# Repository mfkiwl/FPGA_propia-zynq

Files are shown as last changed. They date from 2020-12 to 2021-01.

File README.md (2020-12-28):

# FPGA_propia
 En este repositorio se subirán los ficheros que permitirán crear una FPGA basada en Zynq-7000

Todo el desarrollo está hecho con KiCad (software libre) para que cualquiera pueda replicarla o mejorarla a su gusto con los ficheros que se van a publicar

## Libreria
El fichero tiene una librería llamada 'Zynq-7000' en la que está el symbol de un XC7Z010 del cual se implementará la versión CLG400 (400 pines en formato de soldadura BGA) 
## XC7Z010-BUENO
El símbolo consta de 9 partes, de las que se va a describir su selección a continuación
### - _Símbolo A_
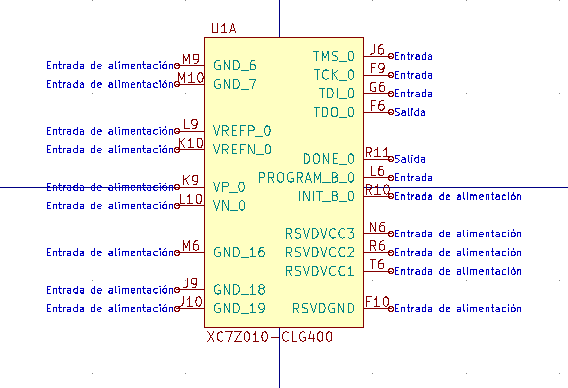
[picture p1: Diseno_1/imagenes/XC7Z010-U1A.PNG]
diseno_A


En este símbolo se reflejan los pines de referencia, además de los pines de depuración TMS, TCK, TDI y TDO. Estos pines pueden necesitar de un cable depurar para cargar el programa o de un USB OTG, que permita evitar tener que usar un cable depurador.

### - _Símbolo B_
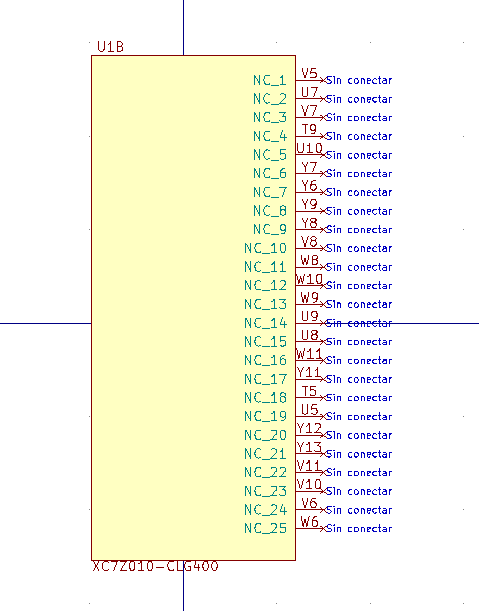
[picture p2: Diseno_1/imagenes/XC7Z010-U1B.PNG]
diseno_B


En este símbolo se reflejan los pines que no tienen conexión

### - _Símbolo c_
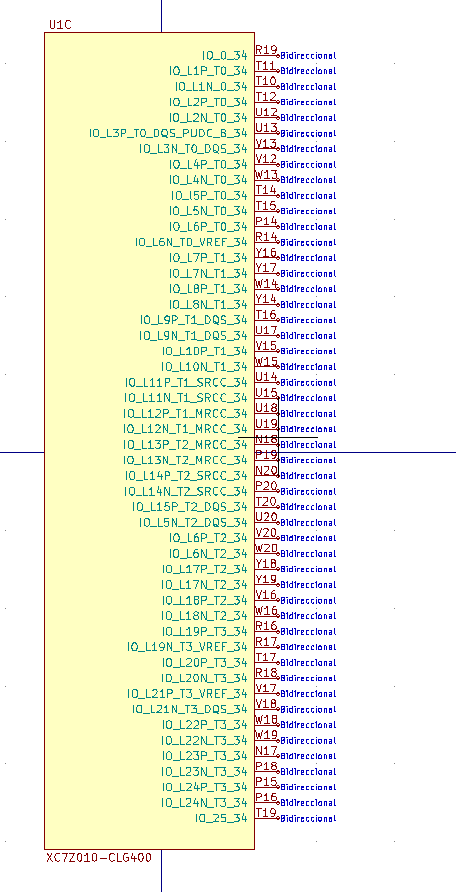
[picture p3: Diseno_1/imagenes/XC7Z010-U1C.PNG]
diseno_C


En este símbolo se reflejan los pines de entrada/salida que se podrán configurar como se quiera

### - _Símbolo D_
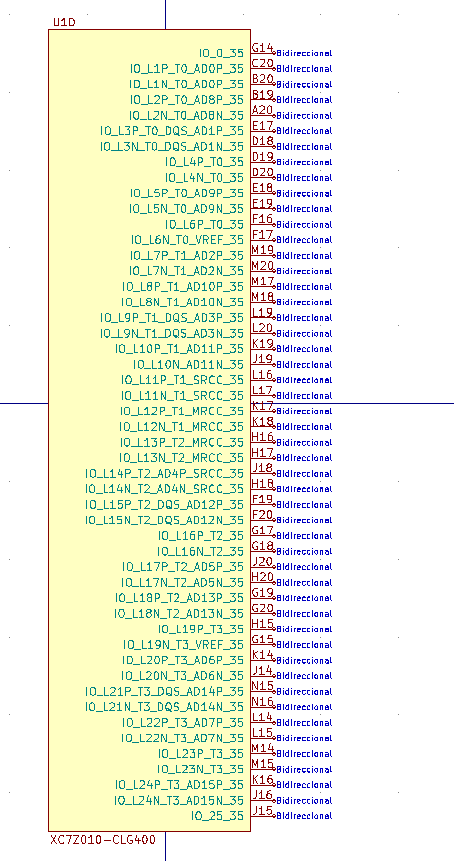
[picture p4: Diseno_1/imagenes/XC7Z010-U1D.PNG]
diseno_D


En este símbolo se reflejan los pines de entrada/salida que se podrán configurar como se quiera

### - _Símbolo E_
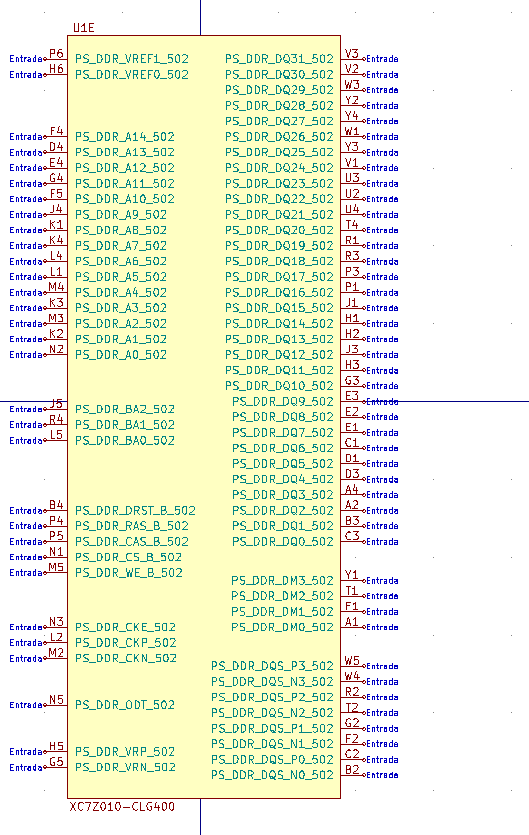
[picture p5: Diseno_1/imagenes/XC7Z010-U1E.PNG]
diseno_E


En este símbolo se reflejan los pines que van a ir a la/las memoria ram. A los pines de la ram se pueden unir varias memorias para aumentar su tamaño.

### - _Símbolo F_
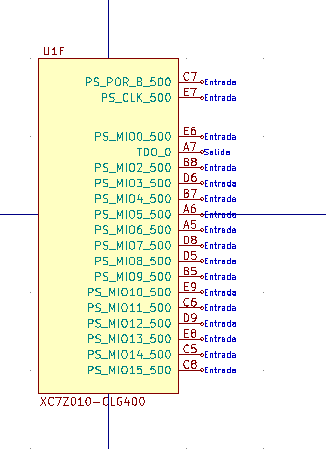
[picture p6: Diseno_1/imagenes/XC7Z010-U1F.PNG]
diseno_F


En este símbolo se reflejan los pines MIO

### - _Símbolo G_
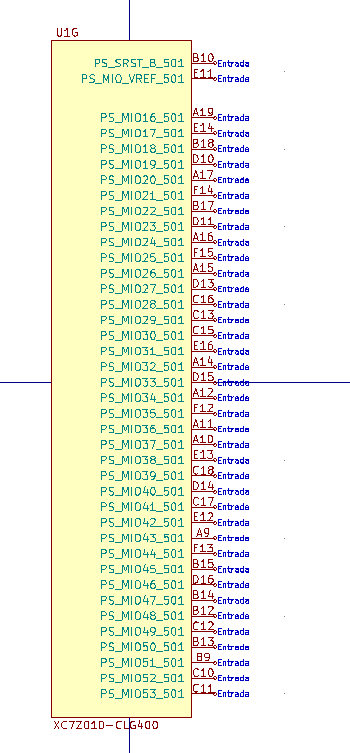
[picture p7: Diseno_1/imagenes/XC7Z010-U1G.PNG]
diseno_G


En este símbolo se reflejan los pines MIO continuación de los anteriores

### - _Símbolo H_
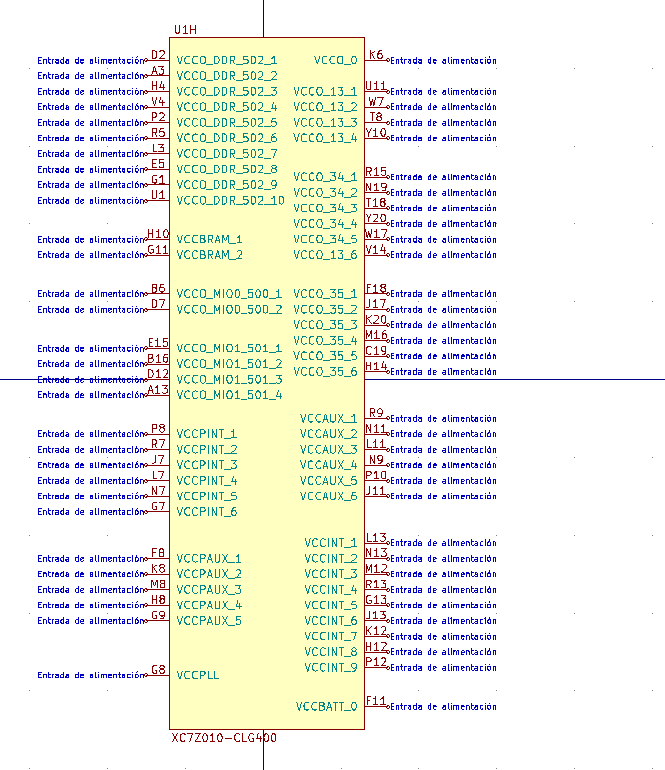
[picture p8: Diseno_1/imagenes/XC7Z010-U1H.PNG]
diseno_F


En este símbolo se reflejan las alimentaciones de cada parte del integrado. Hay que tener en cuenta que cada parte tiene una alimentación distinta, la VCCO_BRAM y los VCCO_PINT de 1V, los VCCO_MIO 3.3V, los VCCO_DDR de 1.35V y los VCCAUX y los VCCPAUX de 1.8V

### - _Símbolo I_
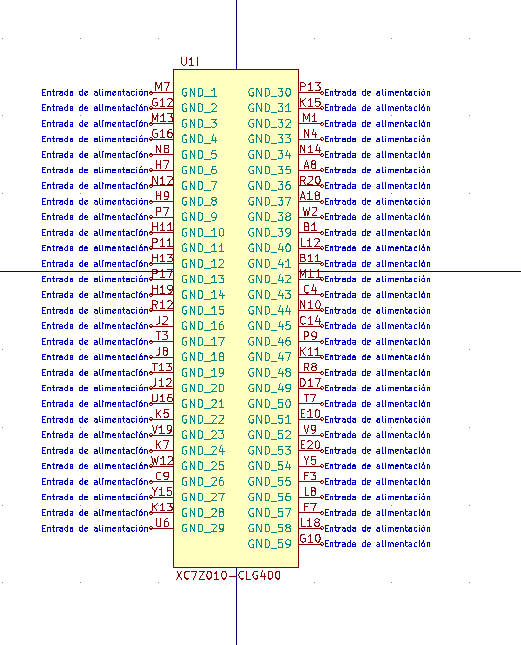
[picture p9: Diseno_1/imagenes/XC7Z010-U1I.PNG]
diseno_I


En este símbolo se reflejan las masas de todo el integrado. Todas las masas van unidas a mismo punto.

### - *Formato del integrado*
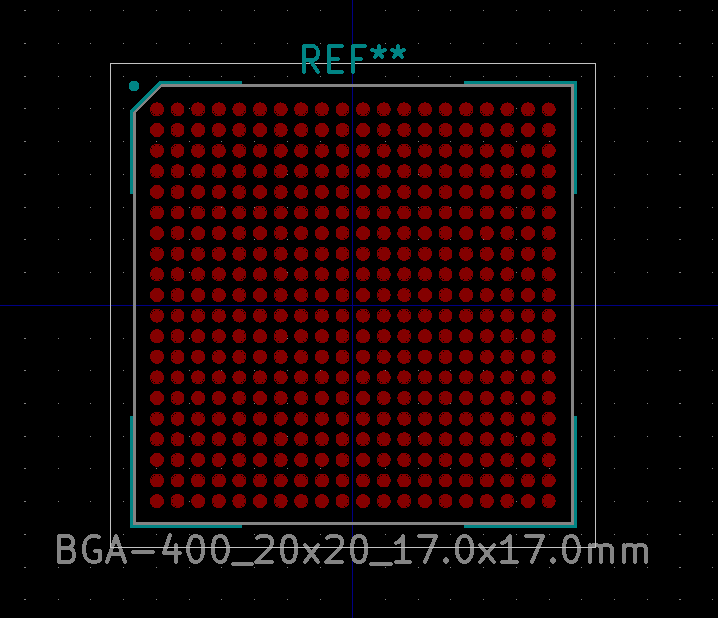
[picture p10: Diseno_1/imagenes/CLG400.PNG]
CLG400


En esta imagen se refleja como es el integrado CLG400 de 400 pines(20x20) para BGA

*** Toda la documentación del frabicante se puede obtener del siguiente enlace: ***
Documentación para el empaquetado: https://www.xilinx.com/support/documentation/user_guides/ug865-Zynq-7000-Pkg-Pinout.pdf
Documentación de los pines: https://www.xilinx.com/support/packagefiles/z7packages/xc7z010clg400pkg.txt

## Memoria RAM
Para la memoria ram se utiliza una MT4K256M16TW-107:P
### Datasheet
http://www.farnell.com/datasheets/3151560.pdf
### Símbolo
El símbolo utilizado es el siguiente
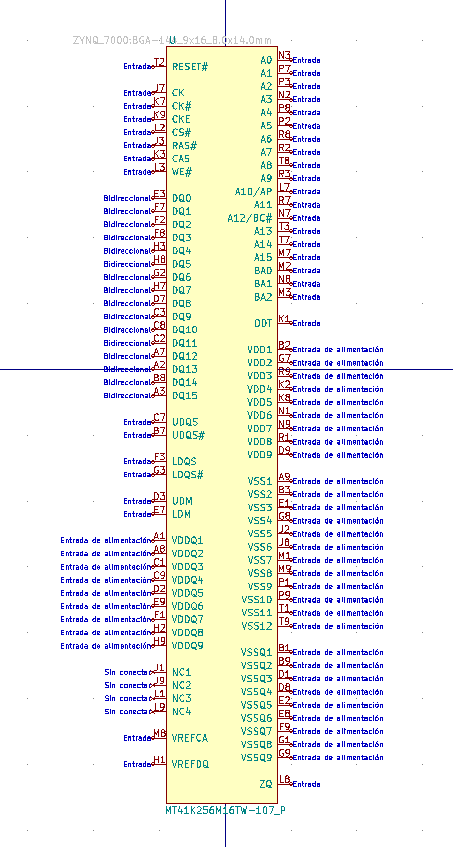
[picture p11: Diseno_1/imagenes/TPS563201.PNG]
Memoria Ram

### Huella
La huella de la memoria ram consta de una matriz de 6x16 que está fragmetada en dos partes separadas por una zona en la que van 3 columnas de pines vacías.
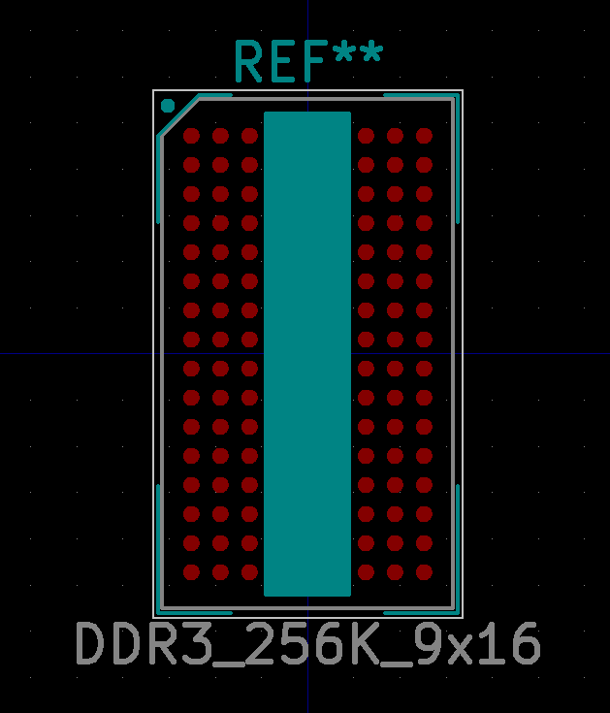
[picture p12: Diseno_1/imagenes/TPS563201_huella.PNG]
Huella Memoria Ram


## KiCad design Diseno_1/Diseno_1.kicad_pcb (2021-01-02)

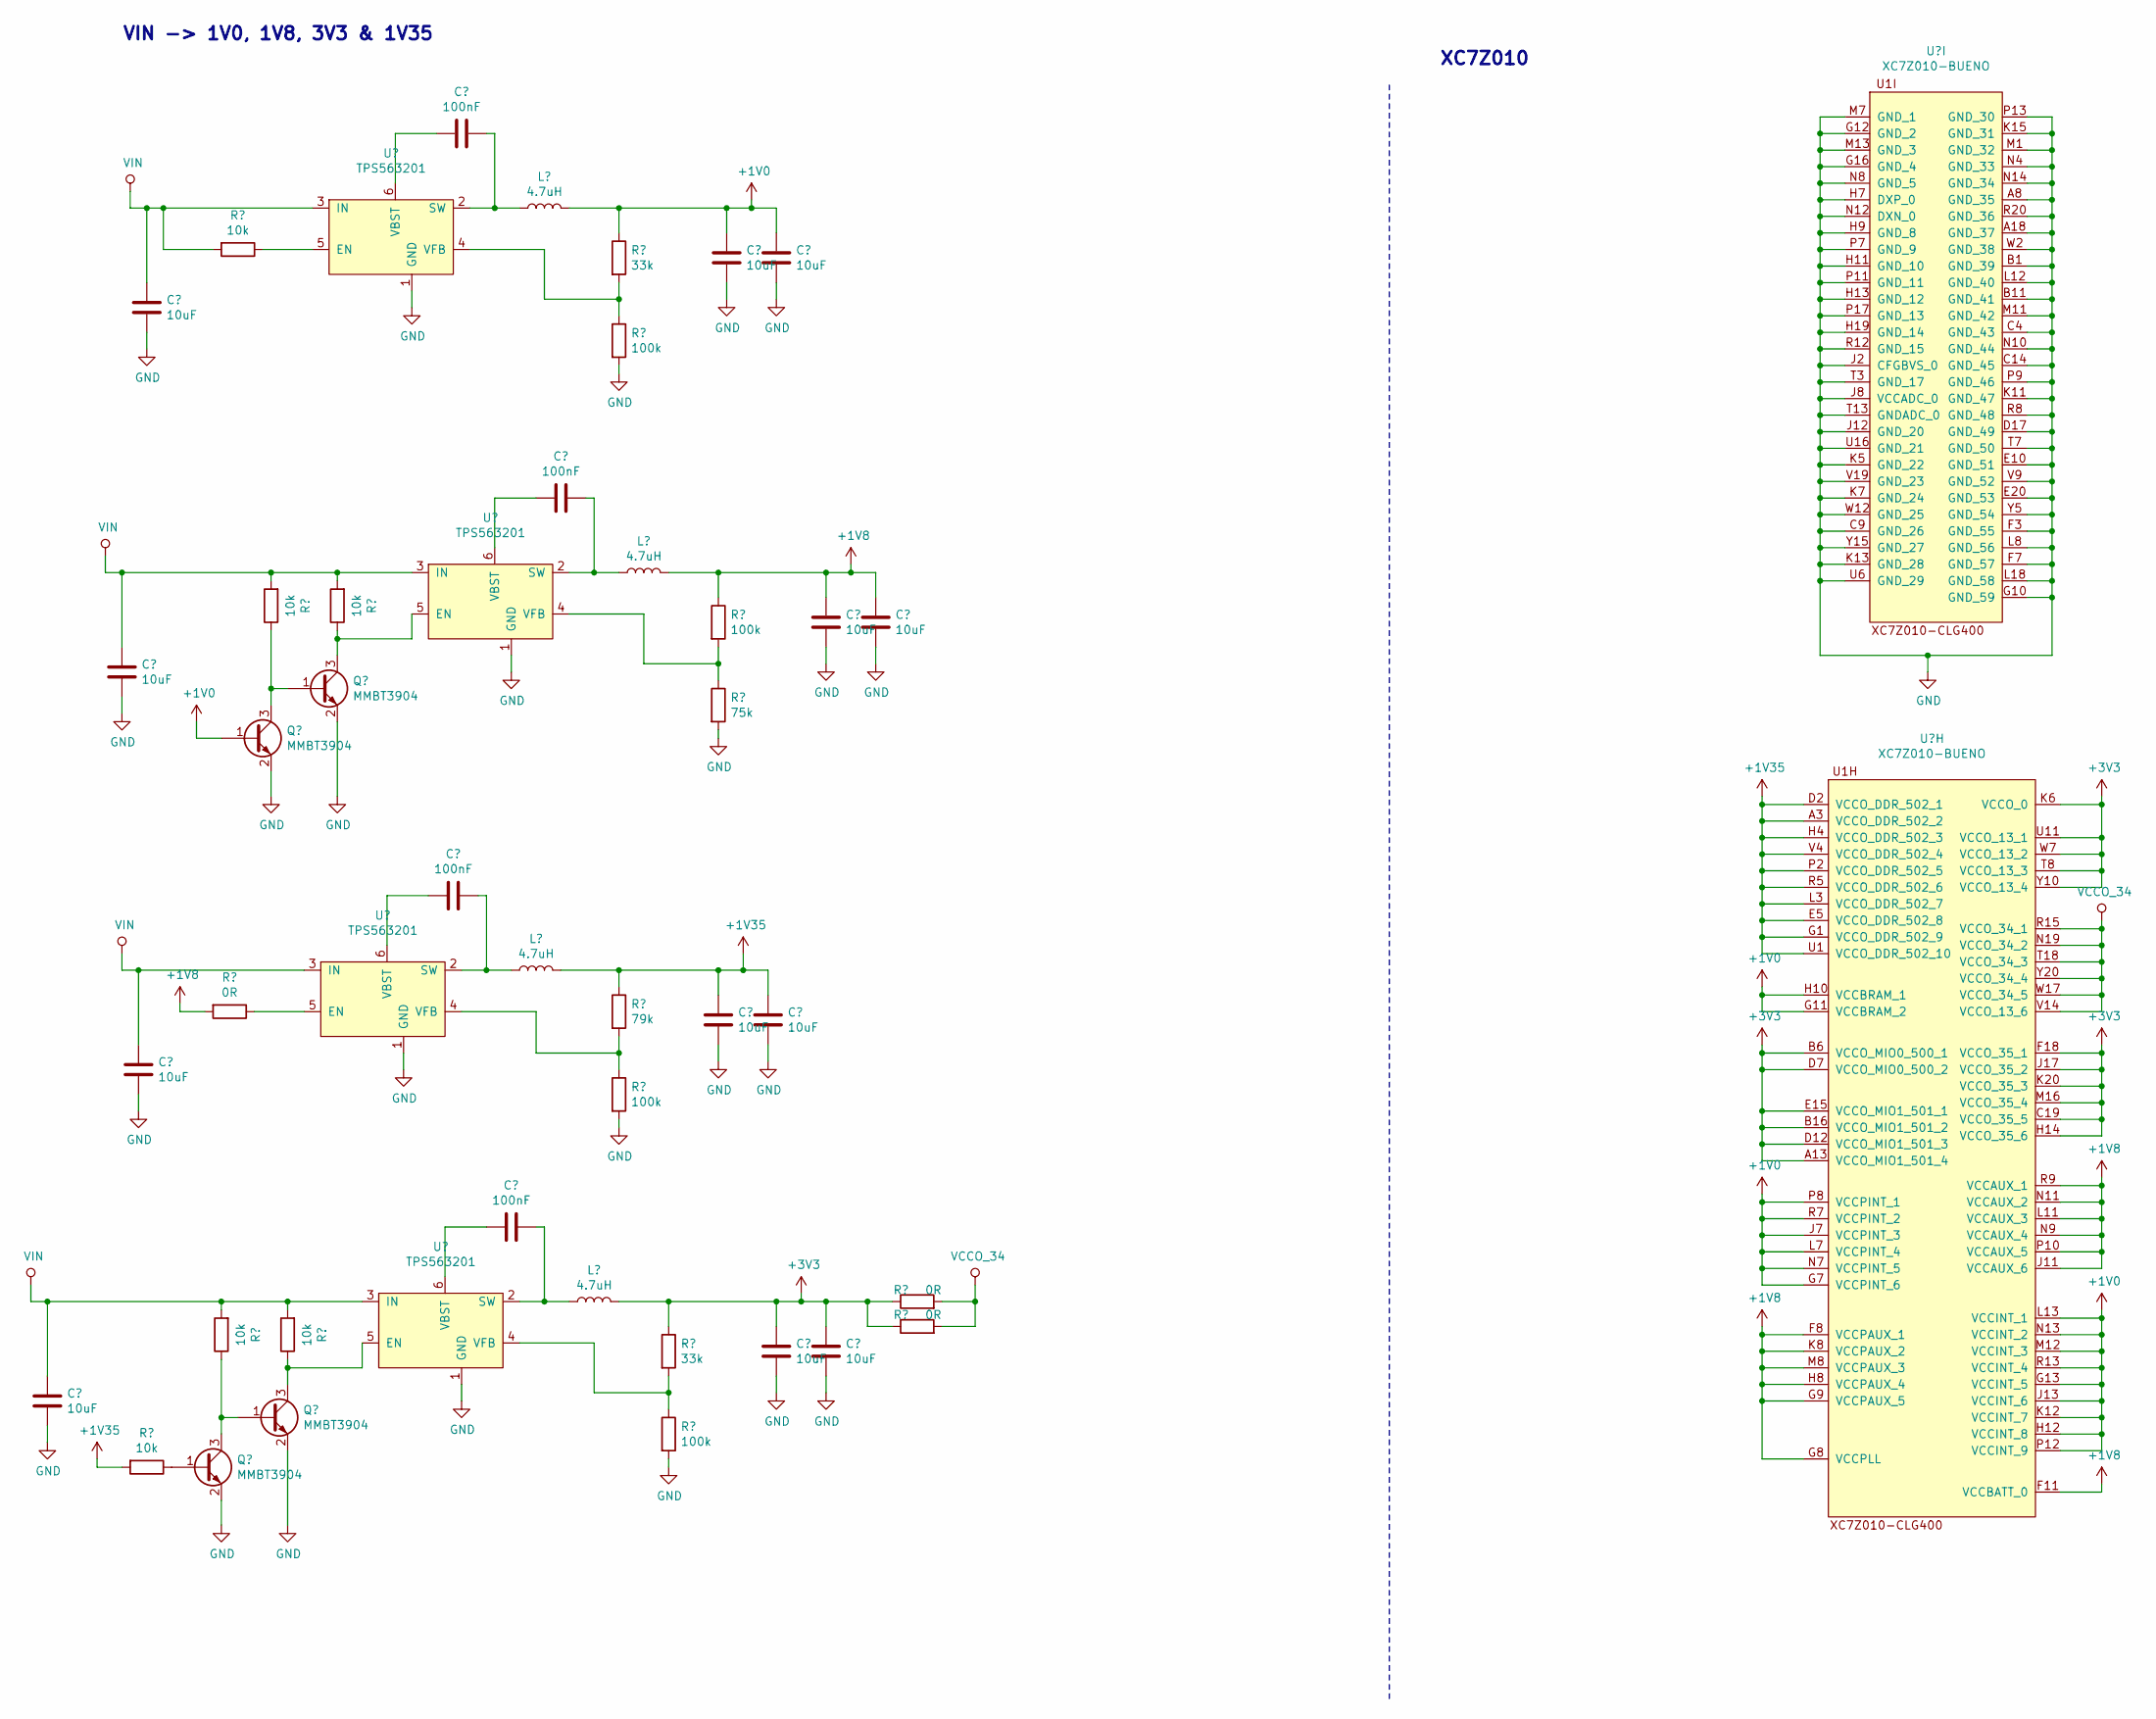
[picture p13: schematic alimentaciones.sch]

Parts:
C1, C2, C3, C4, C9, C10, C11, C12, C13, C14, C15, C16: 10uF; C_0805_2012Metric
C5, C6, C7, C8: 100nF; C_0805_2012Metric
L1, L2, L3, L4: 4.7uH; L_0805_2012Metric
Q1, Q2, Q3, Q4: MMBT3904; SOT-23
R1, R2, R4, R5, R6, R7: 10k; R_0805_2012Metric
R3, R16, R17: 0R; R_0805_2012Metric
R8, R12: 33k; R_0805_2012Metric
R9, R11, R13, R14: 100k; R_0805_2012Metric
R10: 79k; R_0805_2012Metric
R15: 75k; R_0805_2012Metric
U1, U2, U3, U4: TPS563201
U5: XC7Z010-BUENO; BGA-400_20x20_17.0x17.0mm

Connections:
+1V0: C10.1, C12.1, L2.2, Q2.1 (B), R8.1, U5.G7 (VCCPINT_6), U5.G11 (VCCBRAM_2), U5.G13 (VCCINT_5), U5.H10 (VCCBRAM_1), U5.H12 (VCCINT_8), U5.J7 (VCCPINT_3), U5.J13 (VCCINT_6), U5.K12 (VCCINT_7), U5.L7 (VCCPINT_4), U5.L13 (VCCINT_1), U5.M12 (VCCINT_3), U5.N7 (VCCPINT_5), U5.N13 (VCCINT_2), U5.P8 (VCCPINT_1), U5.P12 (VCCINT_9), U5.R7 (VCCPINT_2), U5.R13 (VCCINT_4)
+1V8: C14.1, C16.1, L4.2, R3.2, R14.1, U5.F8 (VCCPAUX_1), U5.F11 (VCCBATT_0), U5.G8 (VCCPLL), U5.G9 (VCCPAUX_5), U5.H8 (VCCPAUX_4), U5.J11 (VCCAUX_6), U5.K8 (VCCPAUX_2), U5.L11 (VCCAUX_3), U5.M8 (VCCPAUX_3), U5.N9 (VCCAUX_4), U5.N11 (VCCAUX_2), U5.P10 (VCCAUX_5), U5.R9 (VCCAUX_1); also elsewhere on the board
+1V35: C9.1, C11.1, L1.2, R1.2, R10.1, U5.A3 (VCCO_DDR_502_2), U5.D2 (VCCO_DDR_502_1), U5.E5 (VCCO_DDR_502_8), U5.G1 (VCCO_DDR_502_9), U5.H4 (VCCO_DDR_502_3), U5.L3 (VCCO_DDR_502_7), U5.P2 (VCCO_DDR_502_5), U5.R5 (VCCO_DDR_502_6), U5.U1 (VCCO_DDR_502_10), U5.V4 (VCCO_DDR_502_4); also elsewhere on the board
GND: C1.2, C2.2, C3.2, C4.2, C9.2, C10.2, C11.2, C12.2, C13.2, C14.2, C15.2, C16.2, Q1.2 (E), Q2.2 (E), Q3.2 (E), Q4.2 (E), R9.2, R11.2, R13.2, R15.2, U1.1 (GND), U2.1 (GND), U3.1 (GND), U4.1 (GND), U5.A8 (GND_35), U5.A18 (GND_37), U5.B1 (GND_39), U5.B11 (GND_41), U5.C4 (GND_43), U5.C9 (GND_26), U5.C14 (GND_45), U5.D17 (GND_49), U5.E10 (GND_51), U5.E20 (GND_53), U5.F3 (GND_55), U5.F7 (GND_57), U5.G10 (GND_59), U5.G12 (GND_2), U5.G16 (GND_4), U5.H7 (DXP_0), U5.H9 (GND_8), U5.H11 (GND_10), U5.H13 (GND_12), U5.H19 (GND_14), U5.J2 (CFGBVS_0), U5.J8 (VCCADC_0), U5.J12 (GND_20), U5.K5 (GND_22), U5.K7 (GND_24), U5.K11 (GND_47), U5.K13 (GND_28), U5.K15 (GND_31), U5.L8 (GND_56), U5.L12 (GND_40), U5.L18 (GND_58), U5.M1 (GND_32), U5.M7 (GND_1), U5.M11 (GND_42), U5.M13 (GND_3), U5.N4 (GND_33), U5.N8 (GND_5), U5.N10 (GND_44), U5.N12 (DXN_0), U5.N14 (GND_34), U5.P7 (GND_9), U5.P9 (GND_46), U5.P11 (GND_11), U5.P13 (GND_30), U5.P17 (GND_13), U5.R8 (GND_48), U5.R12 (GND_15), U5.R20 (GND_36), U5.T3 (GND_17), U5.T7 (GND_50), U5.T13 (GNDADC_0), U5.U6 (GND_29), U5.U16 (GND_21), U5.V9 (GND_52), U5.V19 (GND_23), U5.W2 (GND_38), U5.W12 (GND_25), U5.Y5 (GND_54), U5.Y15 (GND_27); also elsewhere on the board
unnamed: C5.1, L1.1, U1.2 (SW)
unnamed: C5.2, U1.6 (VBST)
unnamed: C6.1, L2.1, U2.2 (SW)
unnamed: C6.2, U2.6 (VBST)
unnamed: C7.1, L3.1, U3.2 (SW)
unnamed: C7.2, U3.6 (VBST)
unnamed: C8.1, L4.1, U4.2 (SW)
unnamed: C8.2, U4.6 (VBST)
unnamed: Q1.1 (B), R1.1
unnamed: Q1.3 (C), Q3.1 (B), R2.1
unnamed: Q2.3 (C), Q4.1 (B), R5.1
unnamed: Q3.3 (C), R6.1, U3.5 (EN)
unnamed: Q4.3 (C), R7.1, U4.5 (EN)
unnamed: R3.1, U1.5 (EN)
unnamed: R4.1, U2.5 (EN)
unnamed: R8.2, R9.1, U2.4 (VFB)
unnamed: R10.2, R11.1, U1.4 (VFB)
unnamed: R12.2, R13.1, U3.4 (VFB)
unnamed: R14.2, R15.1, U4.4 (VFB)

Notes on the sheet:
VIN -> 1V0, 1V8, 3V3 & 1V35
XC7Z010

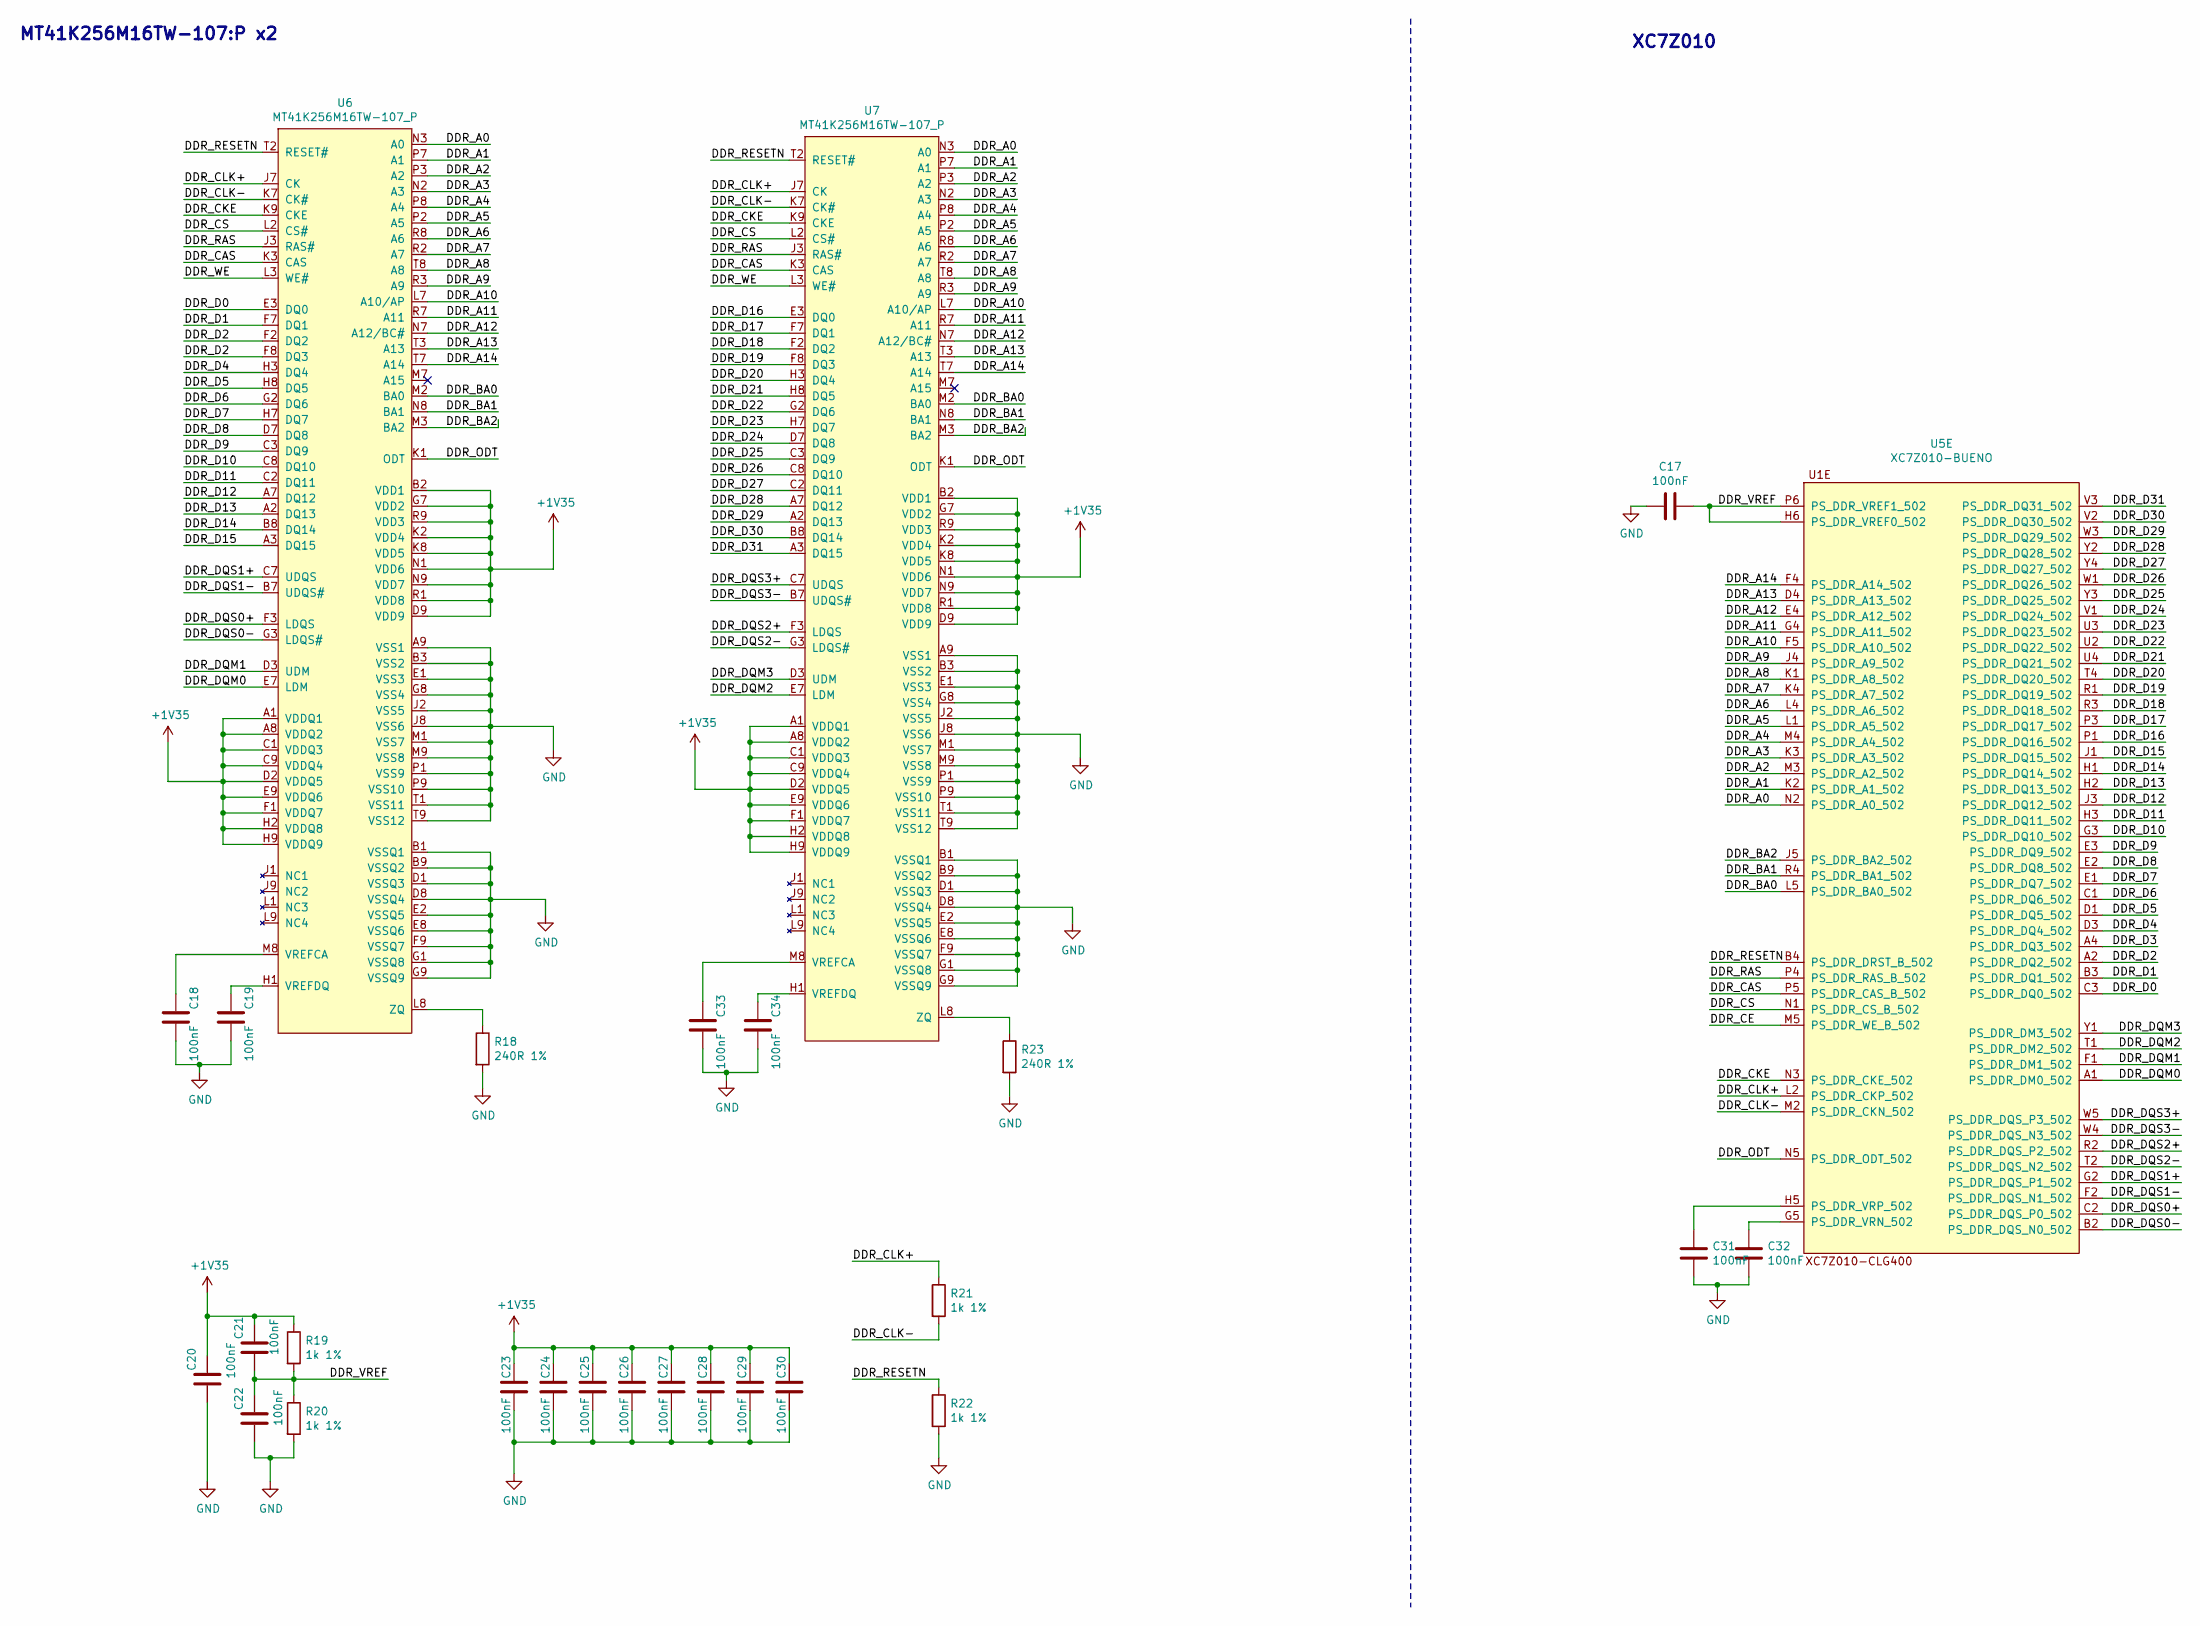
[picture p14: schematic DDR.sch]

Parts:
C17, C18, C19, C20, C21, C22, C23, C24, C25, C26, C27, C28, C29, C30, C31, C32, C33, C34: 100nF; C_0805_2012Metric
R18, R23: 240R 1%; R_0805_2012Metric
R19, R20, R21, R22: 1k 1%; R_0805_2012Metric
U5: XC7Z010-BUENO; BGA-400_20x20_17.0x17.0mm
U6, U7: MT41K256M16TW-107_P; BGA-144_9x16_8.0x14.0mm

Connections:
+1V35: C20.1, C21.1, C23.1, C24.1, C25.1, C26.1, C27.1, C28.1, C29.1, C30.1, R19.1, U6.A1 (VDDQ1), U6.A8 (VDDQ2), U6.B2 (VDD1), U6.C1 (VDDQ3), U6.C9 (VDDQ4), U6.D2 (VDDQ5), U6.D9 (VDD9), U6.E9 (VDDQ6), U6.F1 (VDDQ7), U6.G7 (VDD2), U6.H2 (VDDQ8), U6.H9 (VDDQ9), U6.K2 (VDD4), U6.K8 (VDD5), U6.N1 (VDD6), U6.N9 (VDD7), U6.R1 (VDD8), U6.R9 (VDD3), U7.A1 (VDDQ1), U7.A8 (VDDQ2), U7.B2 (VDD1), U7.C1 (VDDQ3), U7.C9 (VDDQ4), U7.D2 (VDDQ5), U7.D9 (VDD9), U7.E9 (VDDQ6), U7.F1 (VDDQ7), U7.G7 (VDD2), U7.H2 (VDDQ8), U7.H9 (VDDQ9), U7.K2 (VDD4), U7.K8 (VDD5), U7.N1 (VDD6), U7.N9 (VDD7), U7.R1 (VDD8), U7.R9 (VDD3); also elsewhere on the board
/Memoria RAM/DDR_A0: U5.N2 (PS_DDR_A0_502), U6.N3 (A0), U7.N3 (A0)
/Memoria RAM/DDR_A1: U5.K2 (PS_DDR_A1_502), U6.P7 (A1), U7.P7 (A1)
/Memoria RAM/DDR_A2: U5.M3 (PS_DDR_A2_502), U6.P3 (A2), U7.P3 (A2)
/Memoria RAM/DDR_A3: U5.K3 (PS_DDR_A3_502), U6.N2 (A3), U7.N2 (A3)
/Memoria RAM/DDR_A4: U5.M4 (PS_DDR_A4_502), U6.P8 (A4), U7.P8 (A4)
/Memoria RAM/DDR_A5: U5.L1 (PS_DDR_A5_502), U6.P2 (A5), U7.P2 (A5)
/Memoria RAM/DDR_A6: U5.L4 (PS_DDR_A6_502), U6.R8 (A6), U7.R8 (A6)
/Memoria RAM/DDR_A7: U5.K4 (PS_DDR_A7_502), U6.R2 (A7), U7.R2 (A7)
/Memoria RAM/DDR_A8: U5.K1 (PS_DDR_A8_502), U6.T8 (A8), U7.T8 (A8)
/Memoria RAM/DDR_A9: U5.J4 (PS_DDR_A9_502), U6.R3 (A9), U7.R3 (A9)
/Memoria RAM/DDR_A10: U5.F5 (PS_DDR_A10_502), U6.L7 (A10/AP), U7.L7 (A10/AP)
/Memoria RAM/DDR_A11: U5.G4 (PS_DDR_A11_502), U6.R7 (A11), U7.R7 (A11)
/Memoria RAM/DDR_A12: U5.E4 (PS_DDR_A12_502), U6.N7 (A12/BC#), U7.N7 (A12/BC#)
/Memoria RAM/DDR_A13: U5.D4 (PS_DDR_A13_502), U6.T3 (A13), U7.T3 (A13)
/Memoria RAM/DDR_A14: U5.F4 (PS_DDR_A14_502), U6.T7 (A14), U7.T7 (A14)
/Memoria RAM/DDR_BA0: U5.L5 (PS_DDR_BA0_502), U6.M2 (BA0), U7.M2 (BA0)
/Memoria RAM/DDR_BA1: U5.R4 (PS_DDR_BA1_502), U6.N8 (BA1), U7.N8 (BA1)
/Memoria RAM/DDR_BA2: U5.J5 (PS_DDR_BA2_502), U6.M3 (BA2), U7.M3 (BA2)
/Memoria RAM/DDR_CAS: U5.P5 (PS_DDR_CAS_B_502), U6.K3 (CAS), U7.K3 (CAS)
/Memoria RAM/DDR_CKE: U5.N3 (PS_DDR_CKE_502), U6.K9 (CKE), U7.K9 (CKE)
/Memoria RAM/DDR_CLK+: R21.1, U5.L2 (PS_DDR_CKP_502), U6.J7 (CK), U7.J7 (CK)
/Memoria RAM/DDR_CLK-: R21.2, U5.M2 (PS_DDR_CKN_502), U6.K7 (CK#), U7.K7 (CK#)
/Memoria RAM/DDR_CS: U5.N1 (PS_DDR_CS_B_502), U6.L2 (CS#), U7.L2 (CS#)
/Memoria RAM/DDR_D0: U5.C3 (PS_DDR_DQ0_502), U6.E3 (DQ0)
/Memoria RAM/DDR_D1: U5.B3 (PS_DDR_DQ1_502), U6.F7 (DQ1)
/Memoria RAM/DDR_D2: U5.A2 (PS_DDR_DQ2_502), U6.F2 (DQ2), U6.F8 (DQ3)
/Memoria RAM/DDR_D4: U5.D3 (PS_DDR_DQ4_502), U6.H3 (DQ4)
/Memoria RAM/DDR_D5: U5.D1 (PS_DDR_DQ5_502), U6.H8 (DQ5)
/Memoria RAM/DDR_D6: U5.C1 (PS_DDR_DQ6_502), U6.G2 (DQ6)
/Memoria RAM/DDR_D7: U5.E1 (PS_DDR_DQ7_502), U6.H7 (DQ7)
/Memoria RAM/DDR_D8: U5.E2 (PS_DDR_DQ8_502), U6.D7 (DQ8)
/Memoria RAM/DDR_D9: U5.E3 (PS_DDR_DQ9_502), U6.C3 (DQ9)
/Memoria RAM/DDR_D10: U5.G3 (PS_DDR_DQ10_502), U6.C8 (DQ10)
/Memoria RAM/DDR_D11: U5.H3 (PS_DDR_DQ11_502), U6.C2 (DQ11)
/Memoria RAM/DDR_D12: U5.J3 (PS_DDR_DQ12_502), U6.A7 (DQ12)
/Memoria RAM/DDR_D13: U5.H2 (PS_DDR_DQ13_502), U6.A2 (DQ13)
/Memoria RAM/DDR_D14: U5.H1 (PS_DDR_DQ14_502), U6.B8 (DQ14)
/Memoria RAM/DDR_D15: U5.J1 (PS_DDR_DQ15_502), U6.A3 (DQ15)
/Memoria RAM/DDR_D16: U5.P1 (PS_DDR_DQ16_502), U7.E3 (DQ0)
/Memoria RAM/DDR_D17: U5.P3 (PS_DDR_DQ17_502), U7.F7 (DQ1)
/Memoria RAM/DDR_D18: U5.R3 (PS_DDR_DQ18_502), U7.F2 (DQ2)
/Memoria RAM/DDR_D19: U5.R1 (PS_DDR_DQ19_502), U7.F8 (DQ3)
/Memoria RAM/DDR_D20: U5.T4 (PS_DDR_DQ20_502), U7.H3 (DQ4)
/Memoria RAM/DDR_D21: U5.U4 (PS_DDR_DQ21_502), U7.H8 (DQ5)
/Memoria RAM/DDR_D22: U5.U2 (PS_DDR_DQ22_502), U7.G2 (DQ6)
/Memoria RAM/DDR_D23: U5.U3 (PS_DDR_DQ23_502), U7.H7 (DQ7)
/Memoria RAM/DDR_D24: U5.V1 (PS_DDR_DQ24_502), U7.D7 (DQ8)
/Memoria RAM/DDR_D25: U5.Y3 (PS_DDR_DQ25_502), U7.C3 (DQ9)
/Memoria RAM/DDR_D26: U5.W1 (PS_DDR_DQ26_502), U7.C8 (DQ10)
/Memoria RAM/DDR_D27: U5.Y4 (PS_DDR_DQ27_502), U7.C2 (DQ11)
/Memoria RAM/DDR_D28: U5.Y2 (PS_DDR_DQ28_502), U7.A7 (DQ12)
/Memoria RAM/DDR_D29: U5.W3 (PS_DDR_DQ29_502), U7.A2 (DQ13)
/Memoria RAM/DDR_D30: U5.V2 (PS_DDR_DQ30_502), U7.B8 (DQ14)
/Memoria RAM/DDR_D31: U5.V3 (PS_DDR_DQ31_502), U7.A3 (DQ15)
/Memoria RAM/DDR_DQM0: U5.A1 (PS_DDR_DM0_502), U6.E7 (LDM)
/Memoria RAM/DDR_DQM1: U5.F1 (PS_DDR_DM1_502), U6.D3 (UDM)
/Memoria RAM/DDR_DQM2: U5.T1 (PS_DDR_DM2_502), U7.E7 (LDM)
/Memoria RAM/DDR_DQM3: U5.Y1 (PS_DDR_DM3_502), U7.D3 (UDM)
/Memoria RAM/DDR_DQS0+: U5.C2 (PS_DDR_DQS_P0_502), U6.F3 (LDQS)
/Memoria RAM/DDR_DQS0-: U5.B2 (PS_DDR_DQS_N0_502), U6.G3 (LDQS#)
/Memoria RAM/DDR_DQS1+: U5.G2 (PS_DDR_DQS_P1_502), U6.C7 (UDQS)
/Memoria RAM/DDR_DQS1-: U5.F2 (PS_DDR_DQS_N1_502), U6.B7 (UDQS#)
/Memoria RAM/DDR_DQS2+: U5.R2 (PS_DDR_DQS_P2_502), U7.F3 (LDQS)
/Memoria RAM/DDR_DQS2-: U5.T2 (PS_DDR_DQS_N2_502), U7.G3 (LDQS#)
/Memoria RAM/DDR_DQS3+: U5.W5 (PS_DDR_DQS_P3_502), U7.C7 (UDQS)
/Memoria RAM/DDR_DQS3-: U5.W4 (PS_DDR_DQS_N3_502), U7.B7 (UDQS#)
/Memoria RAM/DDR_ODT: U5.N5 (PS_DDR_ODT_502), U6.K1 (ODT), U7.K1 (ODT)
/Memoria RAM/DDR_RAS: U5.P4 (PS_DDR_RAS_B_502), U6.J3 (RAS#), U7.J3 (RAS#)
/Memoria RAM/DDR_RESETN: R22.1, U5.B4 (PS_DDR_DRST_B_502), U6.T2 (RESET#), U7.T2 (RESET#)
/Memoria RAM/DDR_VREF: C17.1, C21.2, C22.1, R19.2, R20.1, U5.H6 (PS_DDR_VREF0_502), U5.P6 (PS_DDR_VREF1_502)
/Memoria RAM/DDR_WE: U6.L3 (WE#), U7.L3 (WE#)
GND: C17.2, C18.2, C19.2, C20.2, C22.2, C23.2, C24.2, C25.2, C26.2, C27.2, C28.2, C29.2, C30.2, C31.2, C32.2, C33.2, C34.2, R18.2, R20.2, R22.2, R23.2, U6.A9 (VSS1), U6.B1 (VSSQ1), U6.B3 (VSS2), U6.B9 (VSSQ2), U6.D1 (VSSQ3), U6.D8 (VSSQ4), U6.E1 (VSS3), U6.E2 (VSSQ5), U6.E8 (VSSQ6), U6.F9 (VSSQ7), U6.G1 (VSSQ8), U6.G8 (VSS4), U6.G9 (VSSQ9), U6.J2 (VSS5), U6.J8 (VSS6), U6.M1 (VSS7), U6.M9 (VSS8), U6.P1 (VSS9), U6.P9 (VSS10), U6.T1 (VSS11), U6.T9 (VSS12), U7.A9 (VSS1), U7.B1 (VSSQ1), U7.B3 (VSS2), U7.B9 (VSSQ2), U7.D1 (VSSQ3), U7.D8 (VSSQ4), U7.E1 (VSS3), U7.E2 (VSSQ5), U7.E8 (VSSQ6), U7.F9 (VSSQ7), U7.G1 (VSSQ8), U7.G8 (VSS4), U7.G9 (VSSQ9), U7.J2 (VSS5), U7.J8 (VSS6), U7.M1 (VSS7), U7.M9 (VSS8), U7.P1 (VSS9), U7.P9 (VSS10), U7.T1 (VSS11), U7.T9 (VSS12); also elsewhere on the board
unnamed: C18.1, U6.M8 (VREFCA)
unnamed: C19.1, U6.H1 (VREFDQ)
unnamed: C31.1, U5.H5 (PS_DDR_VRP_502)
unnamed: C32.1, U5.G5 (PS_DDR_VRN_502)
unnamed: C33.1, U7.M8 (VREFCA)
unnamed: C34.1, U7.H1 (VREFDQ)
unnamed: R18.1, U6.L8 (ZQ)
unnamed: R23.1, U7.L8 (ZQ)

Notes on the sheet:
XC7Z010
MT41K256M16TW-107:P x2

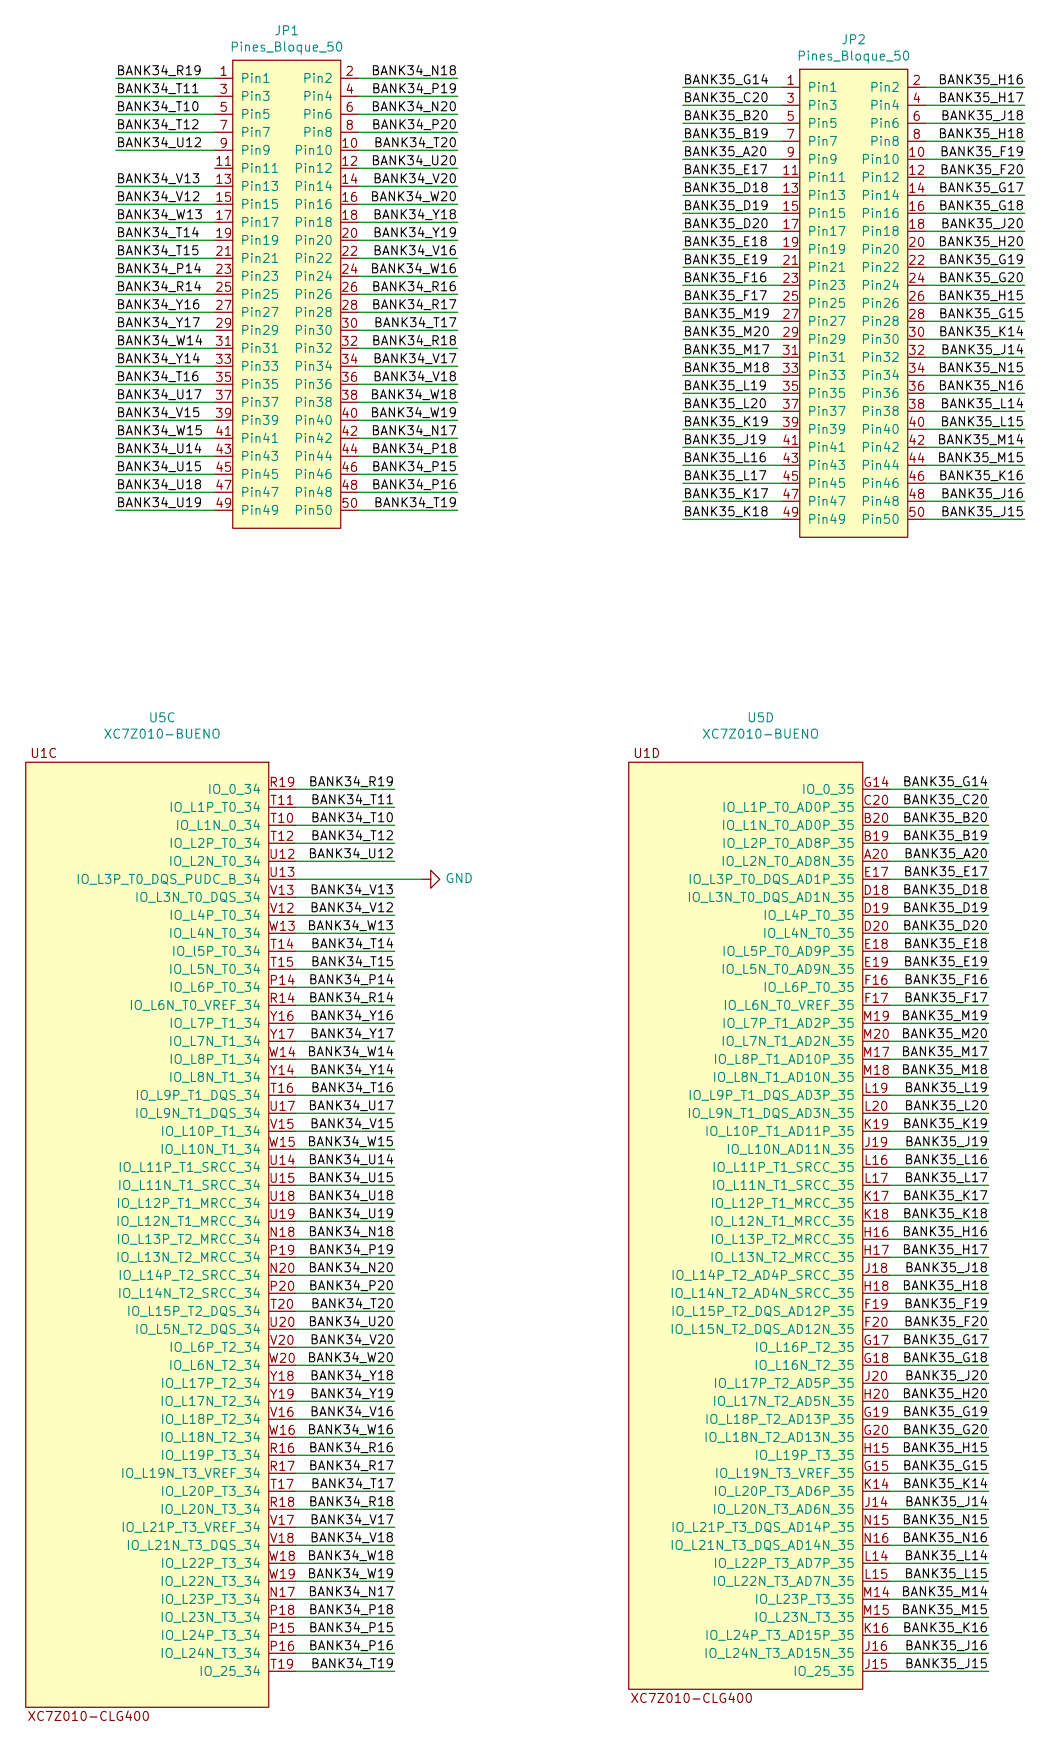
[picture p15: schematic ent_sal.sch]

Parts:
JP1, JP2: Pines_Bloque_50; PINES_50_NUMERO
U5: XC7Z010-BUENO; BGA-400_20x20_17.0x17.0mm

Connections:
/Entradas y Salidas/BANK34_N17: JP1.42 (Pin42), U5.N17 (IO_L23P_T3_34)
/Entradas y Salidas/BANK34_N18: JP1.2 (Pin2), U5.N18 (IO_L13P_T2_MRCC_34)
/Entradas y Salidas/BANK34_N20: JP1.6 (Pin6), U5.N20 (IO_L14P_T2_SRCC_34)
/Entradas y Salidas/BANK34_P14: JP1.23 (Pin23), U5.P14 (IO_L6P_T0_34)
/Entradas y Salidas/BANK34_P15: JP1.46 (Pin46), U5.P15 (IO_L24P_T3_34)
/Entradas y Salidas/BANK34_P16: JP1.48 (Pin48), U5.P16 (IO_L24N_T3_34)
/Entradas y Salidas/BANK34_P18: JP1.44 (Pin44), U5.P18 (IO_L23N_T3_34)
/Entradas y Salidas/BANK34_P19: JP1.4 (Pin4), U5.P19 (IO_L13N_T2_MRCC_34)
/Entradas y Salidas/BANK34_P20: JP1.8 (Pin8), U5.P20 (IO_L14N_T2_SRCC_34)
/Entradas y Salidas/BANK34_R14: JP1.25 (Pin25), U5.R14 (IO_L6N_T0_VREF_34)
/Entradas y Salidas/BANK34_R16: JP1.26 (Pin26), U5.R16 (IO_L19P_T3_34)
/Entradas y Salidas/BANK34_R17: JP1.28 (Pin28), U5.R17 (IO_L19N_T3_VREF_34)
/Entradas y Salidas/BANK34_R18: JP1.32 (Pin32), U5.R18 (IO_L20N_T3_34)
/Entradas y Salidas/BANK34_R19: JP1.1 (Pin1), U5.R19 (IO_0_34)
/Entradas y Salidas/BANK34_T10: JP1.5 (Pin5), U5.T10 (IO_L1N_0_34)
/Entradas y Salidas/BANK34_T11: JP1.3 (Pin3), U5.T11 (IO_L1P_T0_34)
/Entradas y Salidas/BANK34_T12: JP1.7 (Pin7), U5.T12 (IO_L2P_T0_34)
/Entradas y Salidas/BANK34_T14: JP1.19 (Pin19), U5.T14 (IO_l5P_T0_34)
/Entradas y Salidas/BANK34_T15: JP1.21 (Pin21), U5.T15 (IO_L5N_T0_34)
/Entradas y Salidas/BANK34_T16: JP1.35 (Pin35), U5.T16 (IO_L9P_T1_DQS_34)
/Entradas y Salidas/BANK34_T17: JP1.30 (Pin30), U5.T17 (IO_L20P_T3_34)
/Entradas y Salidas/BANK34_T19: JP1.50 (Pin50), U5.T19 (IO_25_34)
/Entradas y Salidas/BANK34_T20: JP1.10 (Pin10), U5.T20 (IO_L15P_T2_DQS_34)
/Entradas y Salidas/BANK34_U12: JP1.9 (Pin9), U5.U12 (IO_L2N_T0_34)
/Entradas y Salidas/BANK34_U14: JP1.43 (Pin43), U5.U14 (IO_L11P_T1_SRCC_34)
/Entradas y Salidas/BANK34_U15: JP1.45 (Pin45), U5.U15 (IO_L11N_T1_SRCC_34)
/Entradas y Salidas/BANK34_U17: JP1.37 (Pin37), U5.U17 (IO_L9N_T1_DQS_34)
/Entradas y Salidas/BANK34_U18: JP1.47 (Pin47), U5.U18 (IO_L12P_T1_MRCC_34)
/Entradas y Salidas/BANK34_U19: JP1.49 (Pin49), U5.U19 (IO_L12N_T1_MRCC_34)
/Entradas y Salidas/BANK34_U20: JP1.12 (Pin12), U5.U20 (IO_L5N_T2_DQS_34)
/Entradas y Salidas/BANK34_V12: JP1.15 (Pin15), U5.V12 (IO_L4P_T0_34)
/Entradas y Salidas/BANK34_V13: JP1.13 (Pin13), U5.V13 (IO_L3N_T0_DQS_34)
/Entradas y Salidas/BANK34_V15: JP1.39 (Pin39), U5.V15 (IO_L10P_T1_34)
/Entradas y Salidas/BANK34_V16: JP1.22 (Pin22), U5.V16 (IO_L18P_T2_34)
/Entradas y Salidas/BANK34_V17: JP1.34 (Pin34), U5.V17 (IO_L21P_T3_VREF_34)
/Entradas y Salidas/BANK34_V18: JP1.36 (Pin36), U5.V18 (IO_L21N_T3_DQS_34)
/Entradas y Salidas/BANK34_V20: JP1.14 (Pin14), U5.V20 (IO_L6P_T2_34)
/Entradas y Salidas/BANK34_W13: JP1.17 (Pin17), U5.W13 (IO_L4N_T0_34)
/Entradas y Salidas/BANK34_W14: JP1.31 (Pin31), U5.W14 (IO_L8P_T1_34)
/Entradas y Salidas/BANK34_W15: JP1.41 (Pin41), U5.W15 (IO_L10N_T1_34)
/Entradas y Salidas/BANK34_W16: JP1.24 (Pin24), U5.W16 (IO_L18N_T2_34)
/Entradas y Salidas/BANK34_W18: JP1.38 (Pin38), U5.W18 (IO_L22P_T3_34)
/Entradas y Salidas/BANK34_W19: JP1.40 (Pin40), U5.W19 (IO_L22N_T3_34)
/Entradas y Salidas/BANK34_W20: JP1.16 (Pin16), U5.W20 (IO_L6N_T2_34)
/Entradas y Salidas/BANK34_Y14: JP1.33 (Pin33), U5.Y14 (IO_L8N_T1_34)
/Entradas y Salidas/BANK34_Y16: JP1.27 (Pin27), U5.Y16 (IO_L7P_T1_34)
/Entradas y Salidas/BANK34_Y17: JP1.29 (Pin29), U5.Y17 (IO_L7N_T1_34)
/Entradas y Salidas/BANK34_Y18: JP1.18 (Pin18), U5.Y18 (IO_L17P_T2_34)
/Entradas y Salidas/BANK34_Y19: JP1.20 (Pin20), U5.Y19 (IO_L17N_T2_34)
/Entradas y Salidas/BANK35_A20: JP2.9 (Pin9), U5.A20 (IO_L2N_T0_AD8N_35)
/Entradas y Salidas/BANK35_B19: JP2.7 (Pin7), U5.B19 (IO_L2P_T0_AD8P_35)
/Entradas y Salidas/BANK35_B20: JP2.5 (Pin5), U5.B20 (IO_L1N_T0_AD0P_35)
/Entradas y Salidas/BANK35_C20: JP2.3 (Pin3), U5.C20 (IO_L1P_T0_AD0P_35)
/Entradas y Salidas/BANK35_D18: JP2.13 (Pin13), U5.D18 (IO_L3N_T0_DQS_AD1N_35)
/Entradas y Salidas/BANK35_D19: JP2.15 (Pin15), U5.D19 (IO_L4P_T0_35)
/Entradas y Salidas/BANK35_D20: JP2.17 (Pin17), U5.D20 (IO_L4N_T0_35)
/Entradas y Salidas/BANK35_E17: JP2.11 (Pin11), U5.E17 (IO_L3P_T0_DQS_AD1P_35)
/Entradas y Salidas/BANK35_E18: JP2.19 (Pin19), U5.E18 (IO_L5P_T0_AD9P_35)
/Entradas y Salidas/BANK35_E19: JP2.21 (Pin21), U5.E19 (IO_L5N_T0_AD9N_35)
/Entradas y Salidas/BANK35_F16: JP2.23 (Pin23), U5.F16 (IO_L6P_T0_35)
/Entradas y Salidas/BANK35_F17: JP2.25 (Pin25), U5.F17 (IO_L6N_T0_VREF_35)
/Entradas y Salidas/BANK35_F19: JP2.10 (Pin10), U5.F19 (IO_L15P_T2_DQS_AD12P_35)
/Entradas y Salidas/BANK35_F20: JP2.12 (Pin12), U5.F20 (IO_L15N_T2_DQS_AD12N_35)
/Entradas y Salidas/BANK35_G14: JP2.1 (Pin1), U5.G14 (IO_0_35)
/Entradas y Salidas/BANK35_G15: JP2.28 (Pin28), U5.G15 (IO_L19N_T3_VREF_35)
/Entradas y Salidas/BANK35_G17: JP2.14 (Pin14), U5.G17 (IO_L16P_T2_35)
/Entradas y Salidas/BANK35_G18: JP2.16 (Pin16), U5.G18 (IO_L16N_T2_35)
/Entradas y Salidas/BANK35_G19: JP2.22 (Pin22), U5.G19 (IO_L18P_T2_AD13P_35)
/Entradas y Salidas/BANK35_G20: JP2.24 (Pin24), U5.G20 (IO_L18N_T2_AD13N_35)
/Entradas y Salidas/BANK35_H15: JP2.26 (Pin26), U5.H15 (IO_L19P_T3_35)
/Entradas y Salidas/BANK35_H16: JP2.2 (Pin2), U5.H16 (IO_L13P_T2_MRCC_35)
/Entradas y Salidas/BANK35_H17: JP2.4 (Pin4), U5.H17 (IO_L13N_T2_MRCC_35)
/Entradas y Salidas/BANK35_H18: JP2.8 (Pin8), U5.H18 (IO_L14N_T2_AD4N_SRCC_35)
/Entradas y Salidas/BANK35_H20: JP2.20 (Pin20), U5.H20 (IO_L17N_T2_AD5N_35)
/Entradas y Salidas/BANK35_J14: JP2.32 (Pin32), U5.J14 (IO_L20N_T3_AD6N_35)
/Entradas y Salidas/BANK35_J15: JP2.50 (Pin50), U5.J15 (IO_25_35)
/Entradas y Salidas/BANK35_J16: JP2.48 (Pin48), U5.J16 (IO_L24N_T3_AD15N_35)
/Entradas y Salidas/BANK35_J18: JP2.6 (Pin6), U5.J18 (IO_L14P_T2_AD4P_SRCC_35)
/Entradas y Salidas/BANK35_J19: JP2.41 (Pin41), U5.J19 (IO_L10N_AD11N_35)
/Entradas y Salidas/BANK35_J20: JP2.18 (Pin18), U5.J20 (IO_L17P_T2_AD5P_35)
/Entradas y Salidas/BANK35_K14: JP2.30 (Pin30), U5.K14 (IO_L20P_T3_AD6P_35)
/Entradas y Salidas/BANK35_K16: JP2.46 (Pin46), U5.K16 (IO_L24P_T3_AD15P_35)
/Entradas y Salidas/BANK35_K17: JP2.47 (Pin47), U5.K17 (IO_L12P_T1_MRCC_35)
/Entradas y Salidas/BANK35_K18: JP2.49 (Pin49), U5.K18 (IO_L12N_T1_MRCC_35)
/Entradas y Salidas/BANK35_K19: JP2.39 (Pin39), U5.K19 (IO_L10P_T1_AD11P_35)
/Entradas y Salidas/BANK35_L14: JP2.38 (Pin38), U5.L14 (IO_L22P_T3_AD7P_35)
/Entradas y Salidas/BANK35_L15: JP2.40 (Pin40), U5.L15 (IO_L22N_T3_AD7N_35)
/Entradas y Salidas/BANK35_L16: JP2.43 (Pin43), U5.L16 (IO_L11P_T1_SRCC_35)
/Entradas y Salidas/BANK35_L17: JP2.45 (Pin45), U5.L17 (IO_L11N_T1_SRCC_35)
/Entradas y Salidas/BANK35_L19: JP2.35 (Pin35), U5.L19 (IO_L9P_T1_DQS_AD3P_35)
/Entradas y Salidas/BANK35_L20: JP2.37 (Pin37), U5.L20 (IO_L9N_T1_DQS_AD3N_35)
/Entradas y Salidas/BANK35_M14: JP2.42 (Pin42), U5.M14 (IO_L23P_T3_35)
/Entradas y Salidas/BANK35_M15: JP2.44 (Pin44), U5.M15 (IO_L23N_T3_35)
/Entradas y Salidas/BANK35_M17: JP2.31 (Pin31), U5.M17 (IO_L8P_T1_AD10P_35)
/Entradas y Salidas/BANK35_M18: JP2.33 (Pin33), U5.M18 (IO_L8N_T1_AD10N_35)
/Entradas y Salidas/BANK35_M19: JP2.27 (Pin27), U5.M19 (IO_L7P_T1_AD2P_35)
/Entradas y Salidas/BANK35_M20: JP2.29 (Pin29), U5.M20 (IO_L7N_T1_AD2N_35)
/Entradas y Salidas/BANK35_N15: JP2.34 (Pin34), U5.N15 (IO_L21P_T3_DQS_AD14P_35)
/Entradas y Salidas/BANK35_N16: JP2.36 (Pin36), U5.N16 (IO_L21N_T3_DQS_AD14N_35)
GND: U5.U13 (IO_L3P_T0_DQS_PUDC_B_34); also elsewhere on the board

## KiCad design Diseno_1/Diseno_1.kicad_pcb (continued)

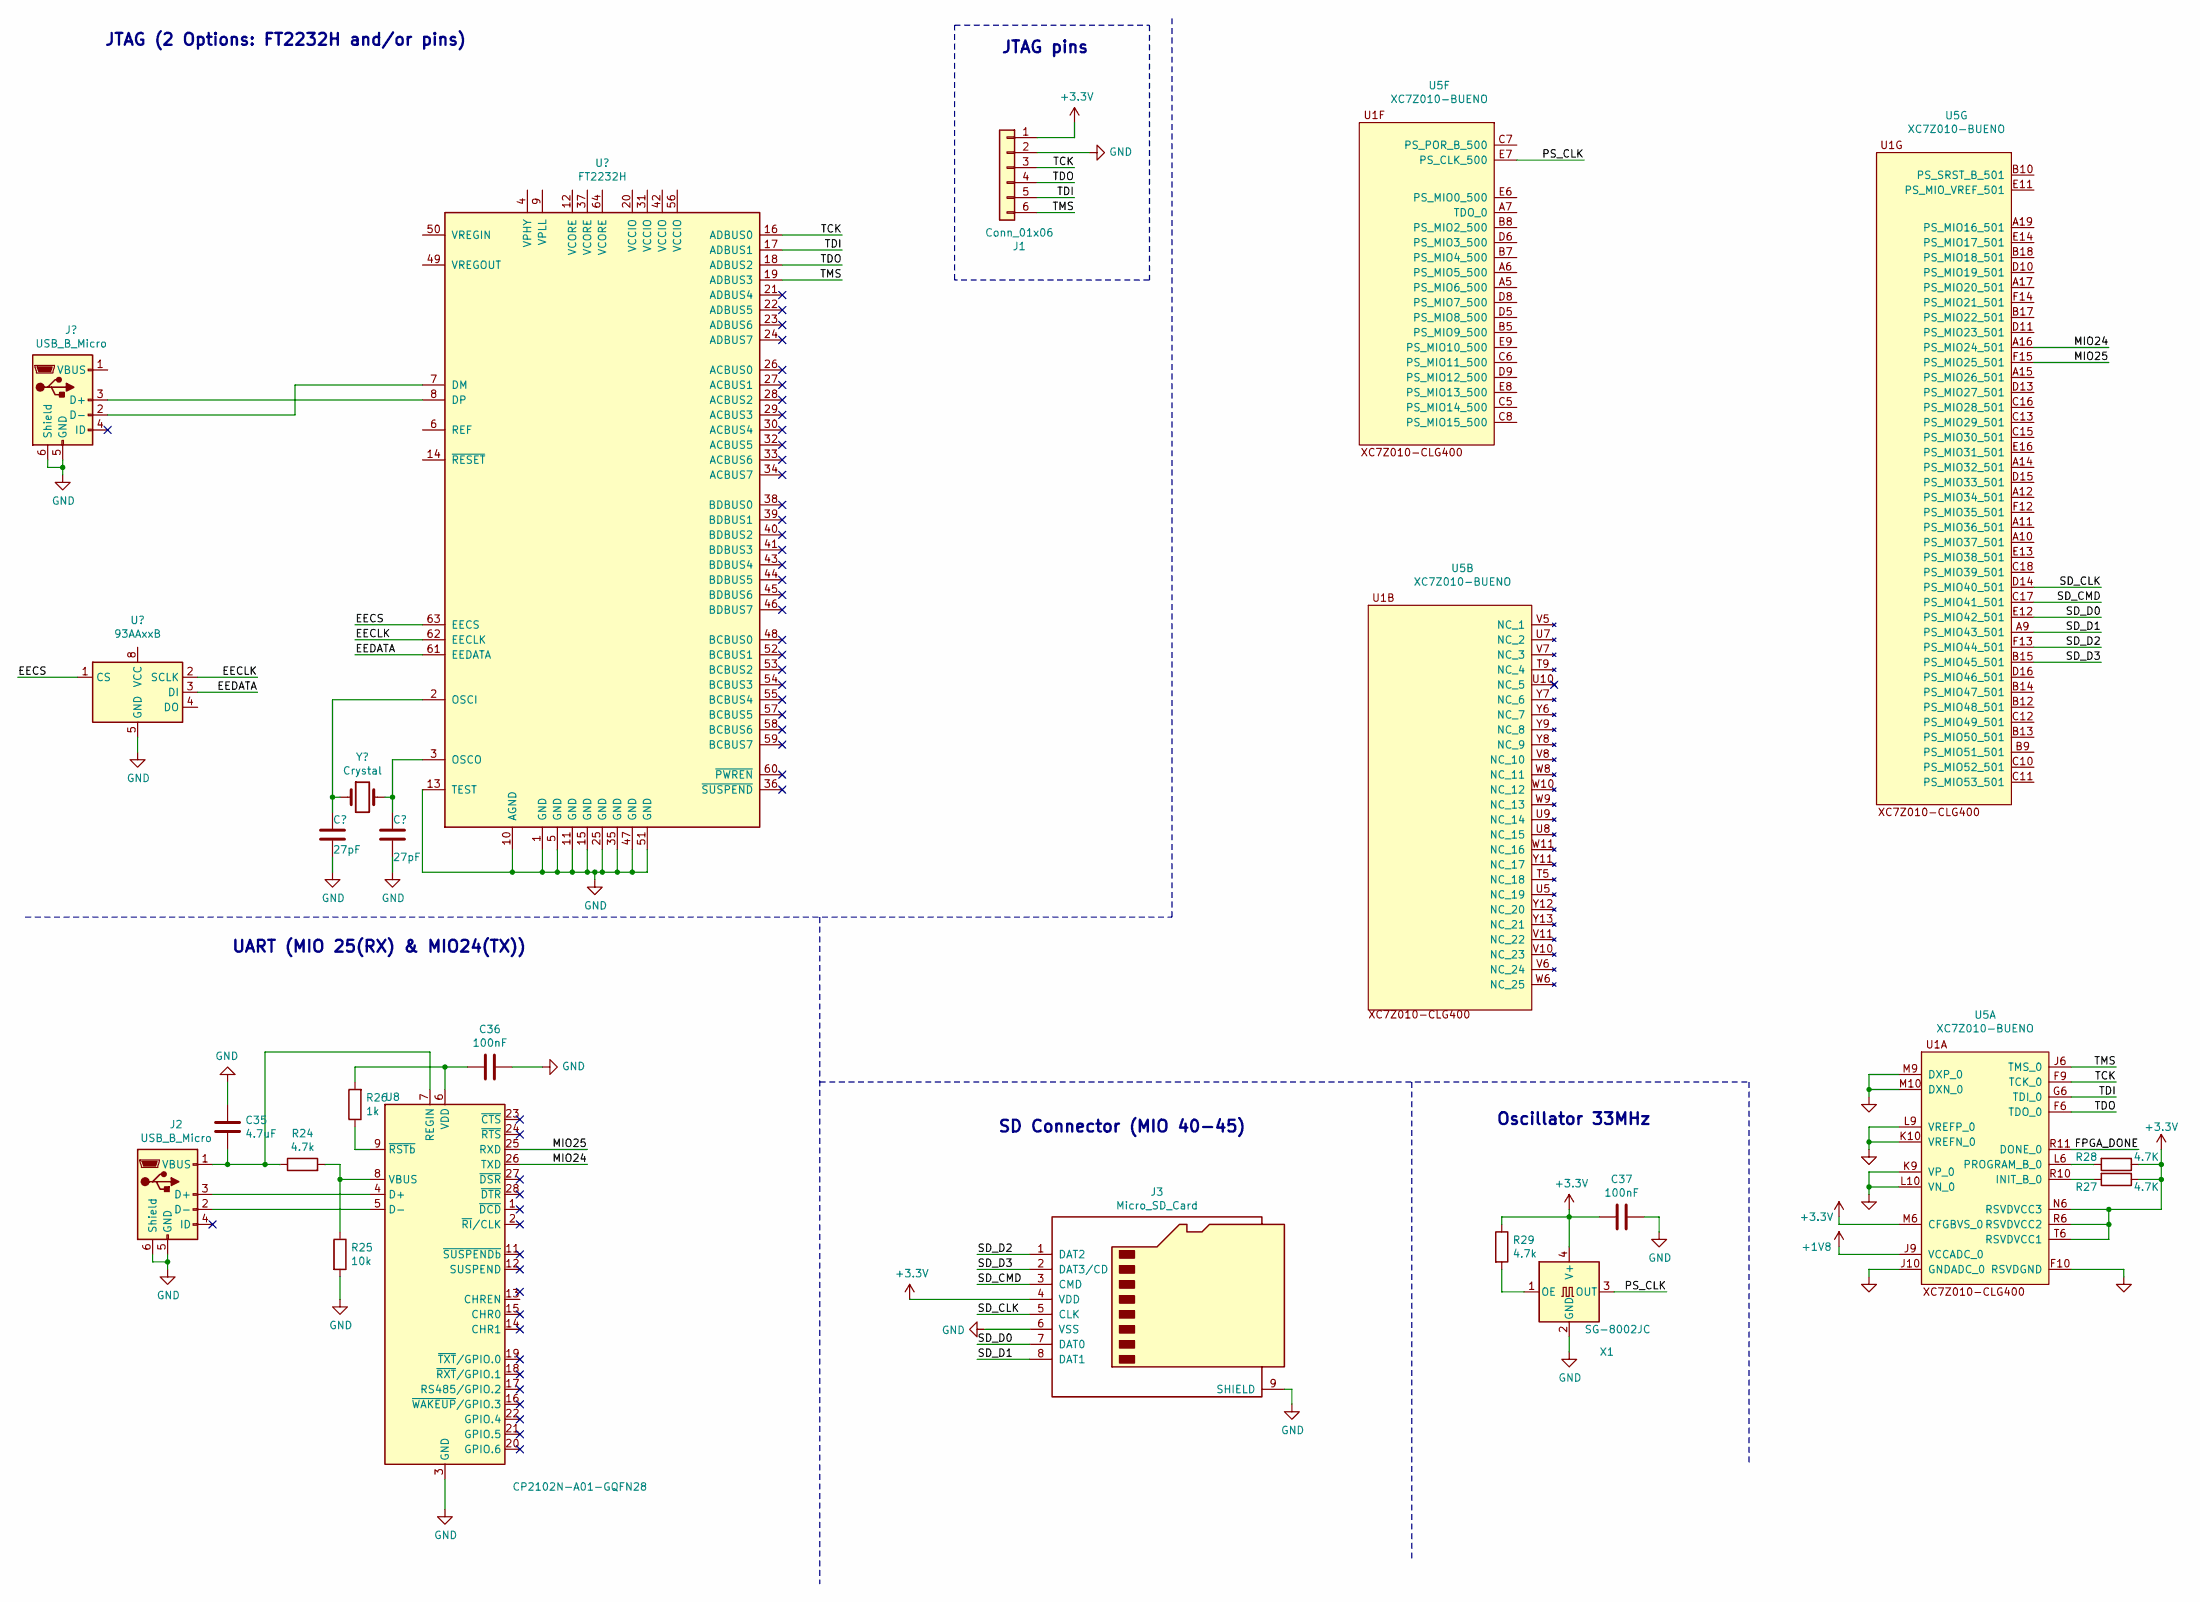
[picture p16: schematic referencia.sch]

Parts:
C35: 4.7uF; R_0805_2012Metric
C36: 100nF; R_0805_2012Metric
C37: 100nF; C_0805_2012Metric
J1: Conn_01x06; PinHeader_1x06_P2.54mm_Vertical
J2: USB_B_Micro; USB_Mini-B_Lumberg_2486_01_Horizontal
J3: Micro_SD_Card; microSD_HC_Wuerth_693072010801
R24, R29: 4.7k; R_0805_2012Metric
R25: 10k; R_0805_2012Metric
R26: 1k; R_0805_2012Metric
R27, R28: 4.7K; R_0805_2012Metric
U5: XC7Z010-BUENO; BGA-400_20x20_17.0x17.0mm
U8: CP2102N-A01-GQFN28; QFN-28-1EP_5x5mm_P0.5mm_EP3.35x3.35mm
X1: SG-8002JC; Oscillator_SMD_SeikoEpson_SG8002JC-4Pin_10.5x5.0mm

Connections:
+1V8: U5.J9 (VCCADC_0); also elsewhere on the board
/Referencias y MIOs/MIO24: U5.A16 (PS_MIO24_501), U8.26 (TXD)
/Referencias y MIOs/MIO25: U5.F15 (PS_MIO25_501), U8.25 (RXD)
/Referencias y MIOs/PS_CLK: U5.E7 (PS_CLK_500), X1.3 (OUT)
/Referencias y MIOs/SD_CLK: J3.5 (CLK), U5.D14 (PS_MIO40_501)
/Referencias y MIOs/SD_CMD: J3.3 (CMD), U5.C17 (PS_MIO41_501)
/Referencias y MIOs/SD_D0: J3.7 (DAT0), U5.E12 (PS_MIO42_501)
/Referencias y MIOs/SD_D1: J3.8 (DAT1), U5.A9 (PS_MIO43_501)
/Referencias y MIOs/SD_D2: J3.1 (DAT2), U5.F13 (PS_MIO44_501)
/Referencias y MIOs/SD_D3: J3.2 (DAT3/CD), U5.B15 (PS_MIO45_501)
/Referencias y MIOs/TCK: J1.3, U5.F9 (TCK_0)
/Referencias y MIOs/TDI: J1.5, U5.G6 (TDI_0)
/Referencias y MIOs/TDO: J1.4, U5.F6 (TDO_0)
/Referencias y MIOs/TMS: J1.6, U5.J6 (TMS_0)
GND: C35.1, C36.1, C37.1, J1.2, J2.5 (GND), J2.6 (Shield), J3.6 (VSS), J3.9 (SHIELD), R25.2, U5.F10 (RSVDGND), U5.J10 (GNDADC_0), U5.K9 (VP_0), U5.K10 (VREFN_0), U5.L9 (VREFP_0), U5.L10 (VN_0), U5.M9 (DXP_0), U5.M10 (DXN_0), U8.3 (GND), U8.29 (GND), X1.2 (GND); also elsewhere on the board
unnamed: C35.2, J2.1 (VBUS), R24.1, U8.7 (REGIN)
unnamed: C36.2, R26.2, U8.6 (VDD)
unnamed: J2.2 (D-), U8.5 (D-)
unnamed: J2.3 (D+), U8.4 (D+)
unnamed: R24.2, R25.1, U8.8 (VBUS)
unnamed: R26.1, U8.9 (~RSTb)
unnamed: R27.2, U5.R10 (INIT_B_0)
unnamed: R28.2, U5.L6 (PROGRAM_B_0)
unnamed: R29.2, X1.1 (OE)

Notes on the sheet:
UART (MIO 25(RX) & MIO24(TX))
SD Connector (MIO 40-45)
Oscillator 33MHz
JTAG pins
JTAG (2 Options: FT2232H and/or pins)

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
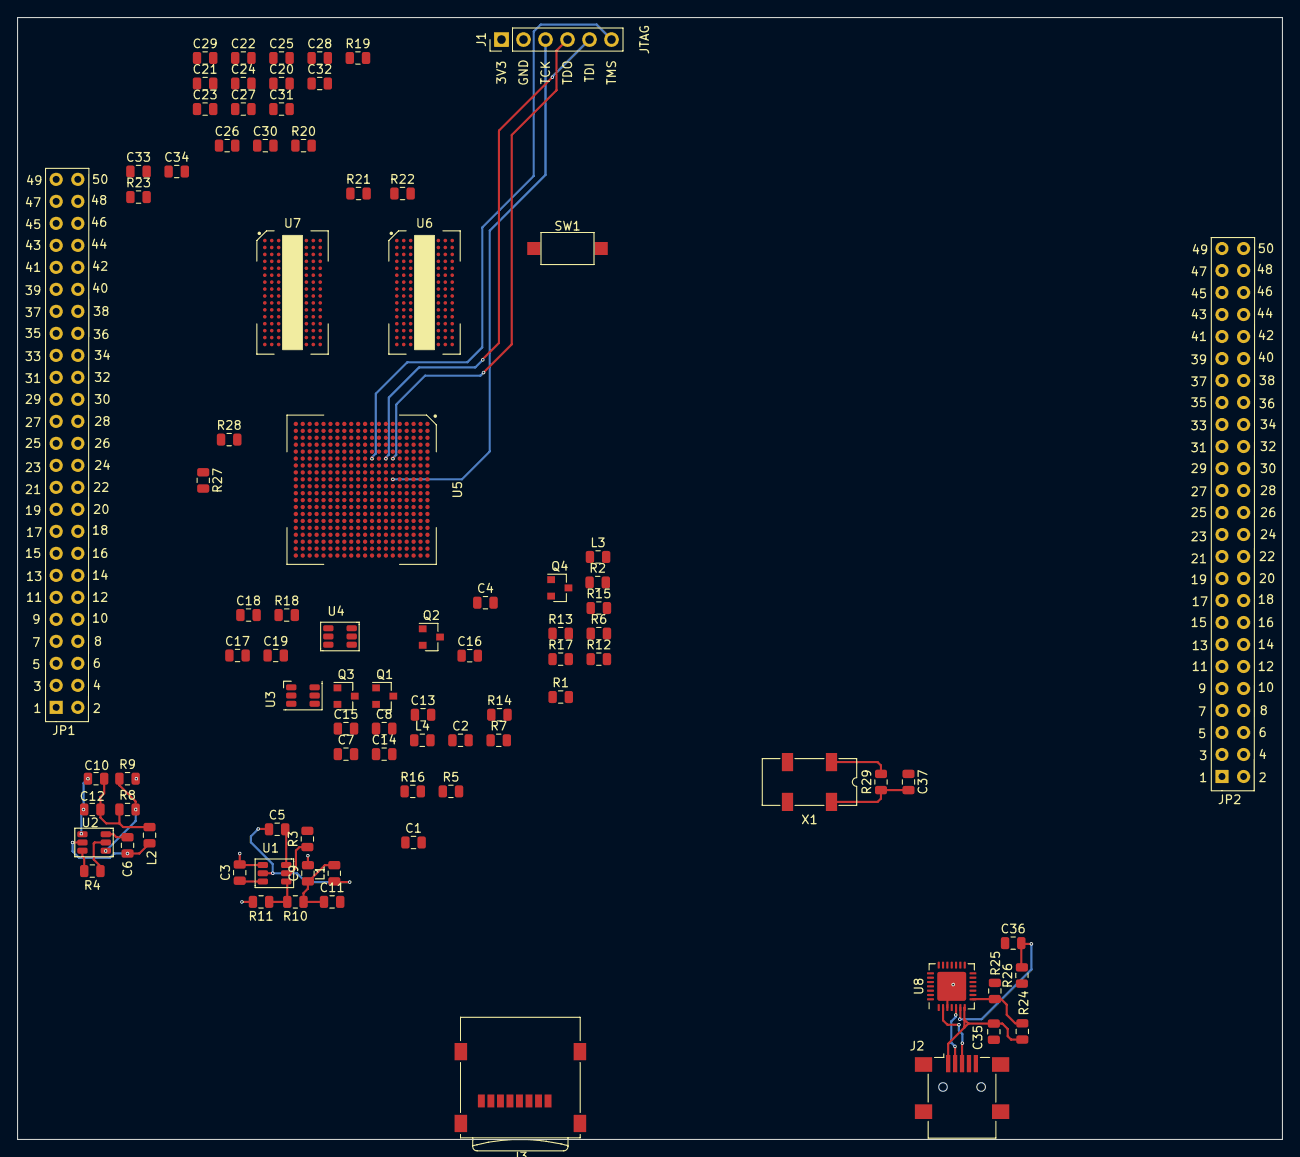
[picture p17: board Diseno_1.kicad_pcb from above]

Board: 2 copper layers, 146.1 x 129.5 mm, 89 parts (0 on the bottom side), 225 nets.

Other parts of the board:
SW1: SW_Push; SW_SPST_CK_RS282G05A3

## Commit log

2020-12-28 extraer cosas in/utiles
    [DDR.sch, MIO.sch, Pines.sch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]
2021-01-02 muchas cosas
    [DDR.sch, Diseno_1.kicad_pcb, Diseno_1.sch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]
